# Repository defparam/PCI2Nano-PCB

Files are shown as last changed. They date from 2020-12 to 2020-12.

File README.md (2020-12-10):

# PCI2Nano Reference Platform

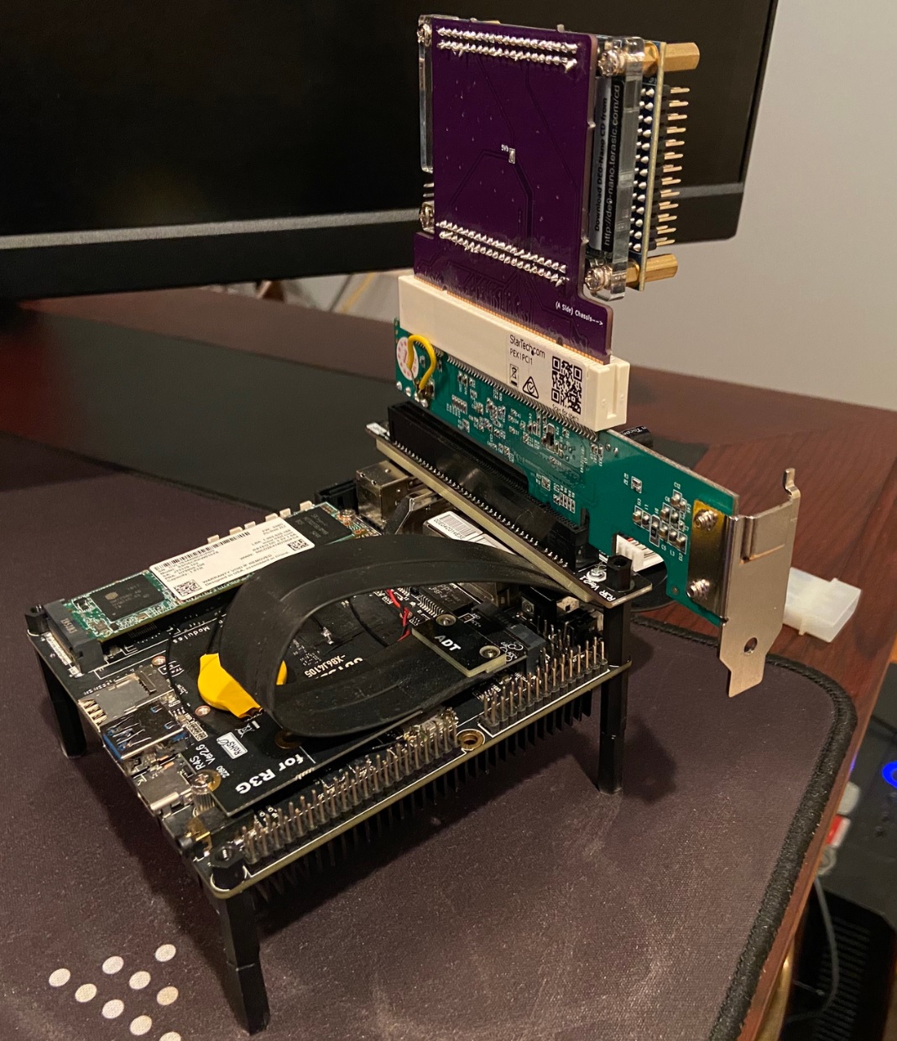
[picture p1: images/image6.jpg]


Welcome to the PCI2Nano Reference Platform repo. In this repo you'll find an inexpensive suggested Reference Platform for designing and testing PCI functions on a DE0-Nano FPGA to an x86 host. I have personally built/connected/tested every single one of these components and can confirm they work for fast iterative PCI development.

The design collateral that is included with this repo are the kicad design files for the PCI2Nano breakout board and a Quartus project that contains all the correct PCI pinout constraints for the PCI2Nano breakout board. This repo does not contain an actual PCI core written in verilog. For an example PCI core implementation with a UART check out the PCI2Nano-RTL repo here: https://github.com/defparam/PCI2Nano-RTL/

<br />This work is licensed under a <a rel="license" href="http://creativecommons.org/licenses/by-sa/4.0/">Creative Commons Attribution-ShareAlike 4.0 International License</a>.

# Demo
My l337-Communication Controller

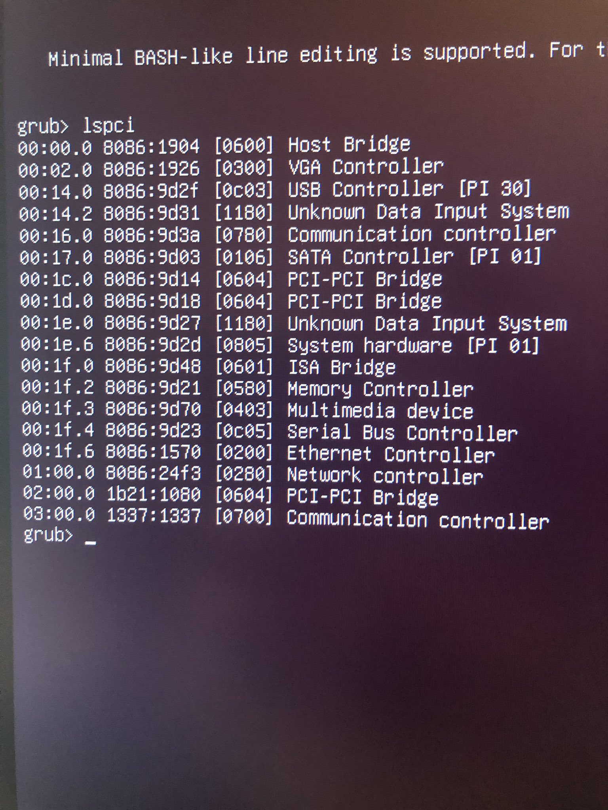
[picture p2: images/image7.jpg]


# Reference Platform Parts List
| Part |  Description| Price | 
|--|--|--|
| DE0-Nano |  FPGA Board|~$100.00
| Seeed Odyssey X86J4105 SBC | SIngle Board Computer | ~$185.00
|PCI2Nano Breakout PCB|Coverts PCI to DE0-Nano GPIO | ~$45 (OSHPark for 3)
|Startech PEX1PCI1| Converts PCIe to PCI | ~$40
|M.2 Key M Extender PCIE x16 | Break out M.2 to PCIe x16 | ~$32
2x 100mil 40-pin IDC sockets| Soldered to the PCB| ~$1-$2

# Directions
1) Mount the Extender cable into the Odyssey M.2 M Key slot. If you have standoffs you can affix the x16 connector of the extender to the SBC as shown in the picture above.
2) Mount the PEX1PCI1 onto the x16 connector. Supplying the molex power I believe is not required since it is used to power the 5V rails of a mounted PCI device, the PCI2Nano doesn't use this 5V rail (unless you bridge it to the Nano's 5V GPIO power pin via the board shunt). However it is best to power the nano through its USB cable
3) Connect the PCI2Nano breakout board to the DE0-Nano, make sure that the USB of the nano points in the correct direction as specified by the silkscreen
4) Connect the PCI side of the PCI2Nano onto the PEX1PCI1, make sure it is connected in the orientation as indicated by the silk screen. The arrow indicating the chassis side should be pointed to the externel side of the PEX1PCI1

# PCB board
There is a small amount of soldering involved with the PCB board to connect the 100mil IDC socket to the PCB board.

# Parts
The DE0-Nano:

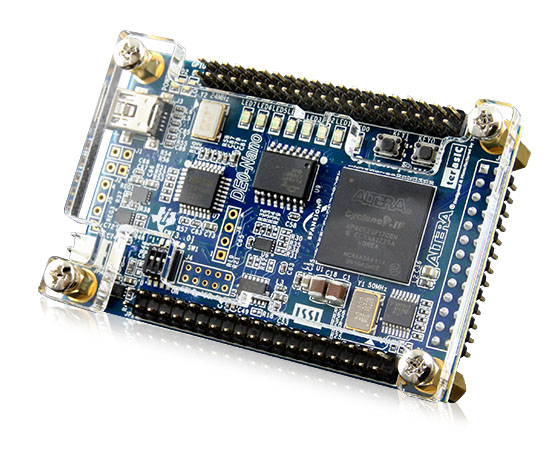
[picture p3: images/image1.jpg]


The PCI2Nano PCB:

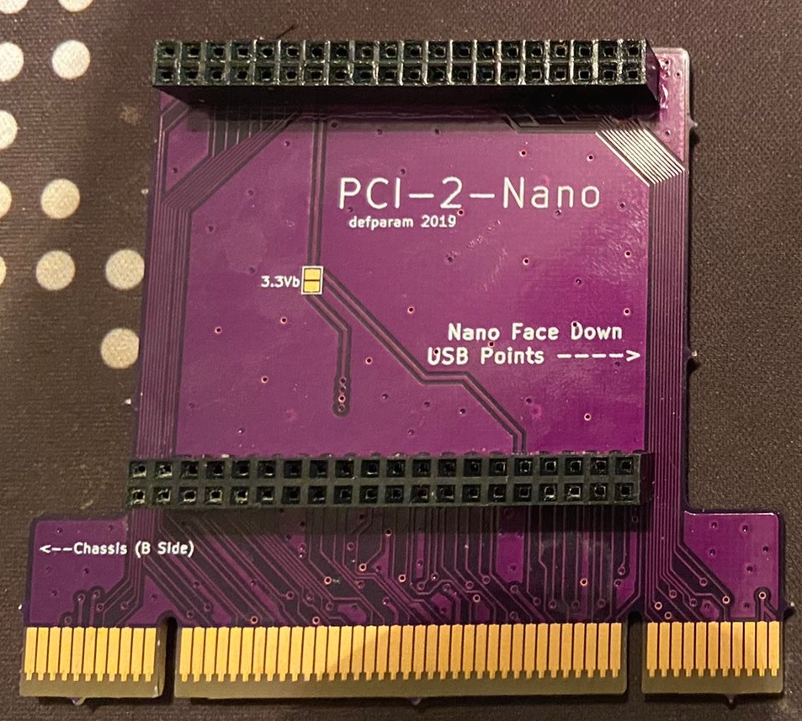
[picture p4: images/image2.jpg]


The PEX1PCI1 PCIe-2-PCI Bridge:

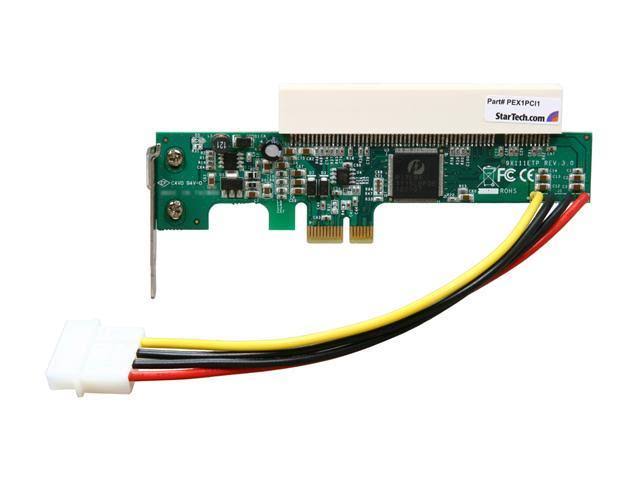
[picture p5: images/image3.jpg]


The Seeed Odyssey X86J4105 SBC:

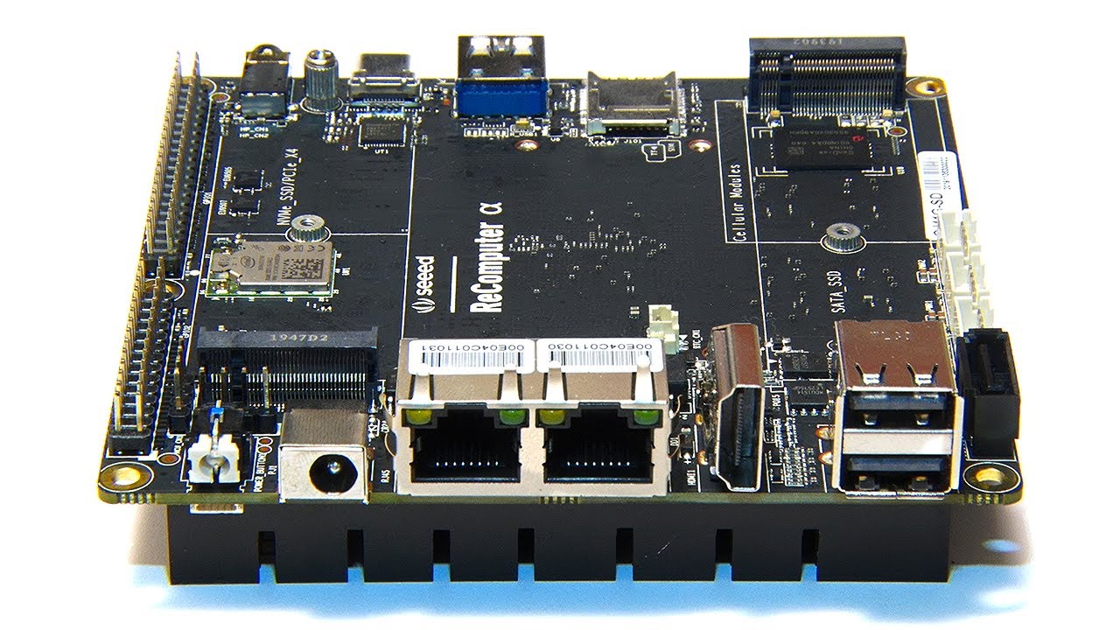
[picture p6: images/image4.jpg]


The M.2 Key M Extender PCIE x16:

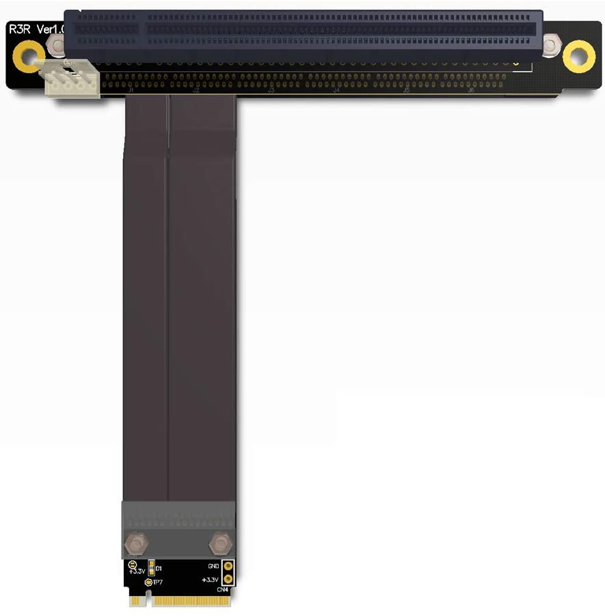
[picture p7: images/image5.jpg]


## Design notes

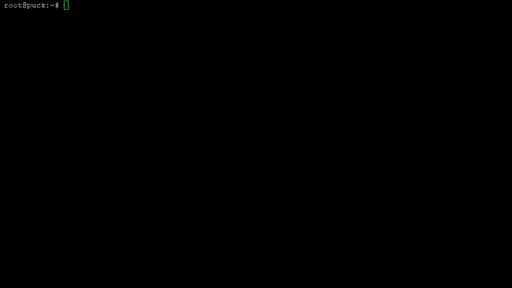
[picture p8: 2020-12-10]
images/pci2nano.gif

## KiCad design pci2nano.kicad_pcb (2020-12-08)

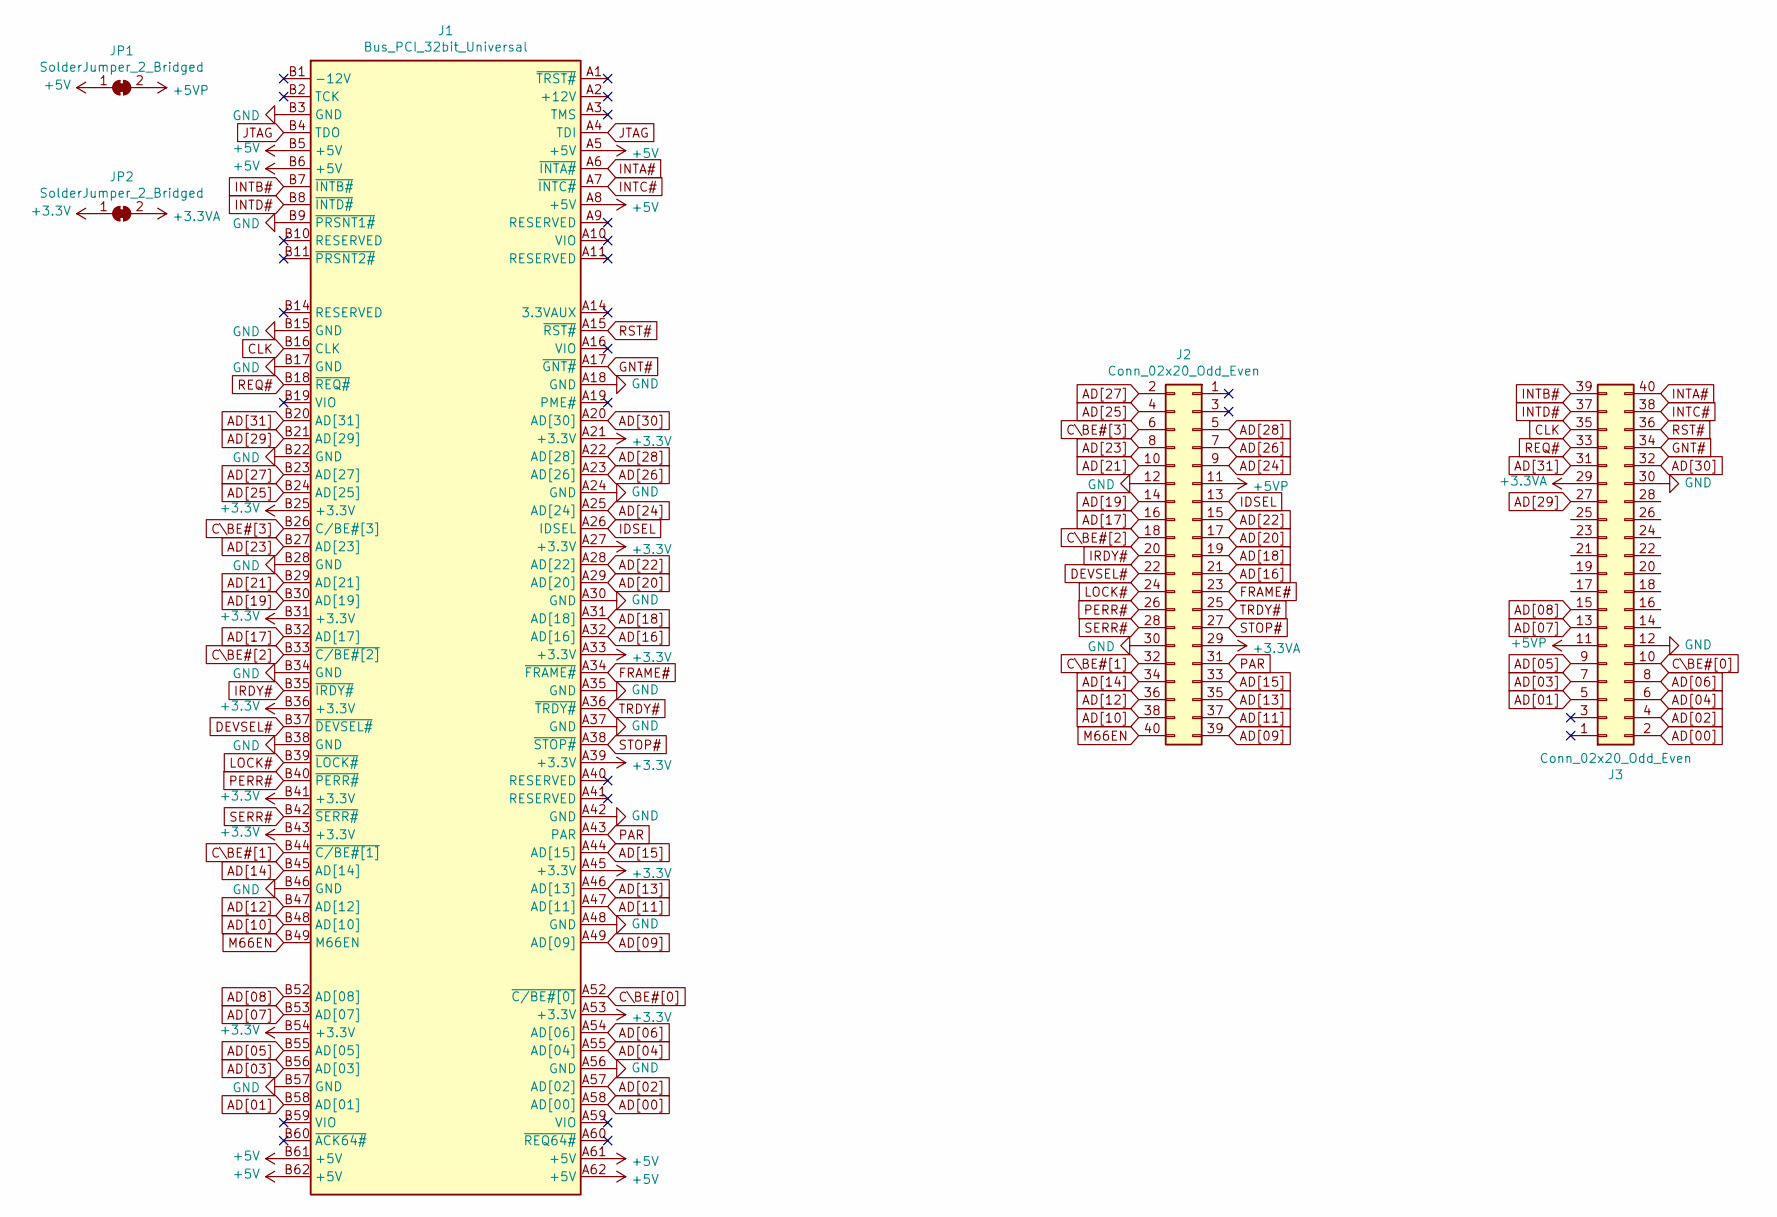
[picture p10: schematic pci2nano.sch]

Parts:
J1: Bus_PCI_32bit_Universal; BUS_PCI_UNIVERSAL
J2, J3: Conn_02x20_Odd_Even; PinHeader_2x20_P2.54mm_Vertical
JP1, JP2: SolderJumper_2_Bridged; SolderJumper-2_P1.3mm_Open_Pad1.0x1.5mm

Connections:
+3.3VA: J2.29, J3.29, JP2.2 (B)
+3V3: J1.A21 (+3.3V), J1.A27 (+3.3V), J1.A33 (+3.3V), J1.A39 (+3.3V), J1.A45 (+3.3V), J1.A53 (+3.3V), J1.B25 (+3.3V), J1.B31 (+3.3V), J1.B36 (+3.3V), J1.B41 (+3.3V), J1.B43 (+3.3V), J1.B54 (+3.3V), JP2.1 (A)
+5V: J1.A5 (+5V), J1.A8 (+5V), J1.A61 (+5V), J1.A62 (+5V), J1.B5 (+5V), J1.B6 (+5V), J1.B61 (+5V), J1.B62 (+5V), JP1.1 (A)
+5VP: J2.11, J3.11, JP1.2 (B)
AD[00]: J1.A58 (AD[00]), J3.2
AD[01]: J1.B58 (AD[01]), J3.5
AD[02]: J1.A57 (AD[02]), J3.4
AD[03]: J1.B56 (AD[03]), J3.7
AD[04]: J1.A55 (AD[04]), J3.6
AD[05]: J1.B55 (AD[05]), J3.9
AD[06]: J1.A54 (AD[06]), J3.8
AD[07]: J1.B53 (AD[07]), J3.13
AD[08]: J1.B52 (AD[08]), J3.15
AD[09]: J1.A49 (AD[09]), J2.39
AD[10]: J1.B48 (AD[10]), J2.38
AD[11]: J1.A47 (AD[11]), J2.37
AD[12]: J1.B47 (AD[12]), J2.36
AD[13]: J1.A46 (AD[13]), J2.35
AD[14]: J1.B45 (AD[14]), J2.34
AD[15]: J1.A44 (AD[15]), J2.33
AD[16]: J1.A32 (AD[16]), J2.21
AD[17]: J1.B32 (AD[17]), J2.16
AD[18]: J1.A31 (AD[18]), J2.19
AD[19]: J1.B30 (AD[19]), J2.14
AD[20]: J1.A29 (AD[20]), J2.17
AD[21]: J1.B29 (AD[21]), J2.10
AD[22]: J1.A28 (AD[22]), J2.15
AD[23]: J1.B27 (AD[23]), J2.8
AD[24]: J1.A25 (AD[24]), J2.9
AD[25]: J1.B24 (AD[25]), J2.4
AD[26]: J1.A23 (AD[26]), J2.7
AD[27]: J1.B23 (AD[27]), J2.2
AD[28]: J1.A22 (AD[28]), J2.5
AD[29]: J1.B21 (AD[29]), J3.27
AD[30]: J1.A20 (AD[30]), J3.32
AD[31]: J1.B20 (AD[31]), J3.31
CLK: J1.B16 (CLK), J3.35
C\BE#[0]: J1.A52 (~C/BE#[0]), J3.10
C\BE#[1]: J1.B44 (~C/BE#[1]), J2.32
C\BE#[2]: J1.B33 (~C/BE#[2]), J2.18
C\BE#[3]: J1.B26 (C/BE#[3]), J2.6
DEVSEL#: J1.B37 (~DEVSEL#), J2.22
FRAME#: J1.A34 (~FRAME#), J2.23
GND: J1.A18 (GND), J1.A24 (GND), J1.A30 (GND), J1.A35 (GND), J1.A37 (GND), J1.A42 (GND), J1.A48 (GND), J1.A56 (GND), J1.B3 (GND), J1.B9 (~PRSNT1#), J1.B15 (GND), J1.B17 (GND), J1.B22 (GND), J1.B28 (GND), J1.B34 (GND), J1.B38 (GND), J1.B46 (GND), J1.B57 (GND), J2.12, J2.30, J3.12, J3.30
GNT#: J1.A17 (~GNT#), J3.34
IDSEL: J1.A26 (IDSEL), J2.13
INTA#: J1.A6 (~INTA#), J3.40
INTB#: J1.B7 (~INTB#), J3.39
INTC#: J1.A7 (~INTC#), J3.38
INTD#: J1.B8 (~INTD#), J3.37
IRDY#: J1.B35 (~IRDY#), J2.20
JTAG: J1.A4 (TDI), J1.B4 (TDO)
LOCK#: J1.B39 (~LOCK#), J2.24
M66EN: J1.B49 (M66EN), J2.40
PAR: J1.A43 (PAR), J2.31
PERR#: J1.B40 (~PERR#), J2.26
REQ#: J1.B18 (~REQ#), J3.33
RST#: J1.A15 (~RST#), J3.36
SERR#: J1.B42 (~SERR#), J2.28
STOP#: J1.A38 (~STOP#), J2.27
TRDY#: J1.A36 (~TRDY#), J2.25

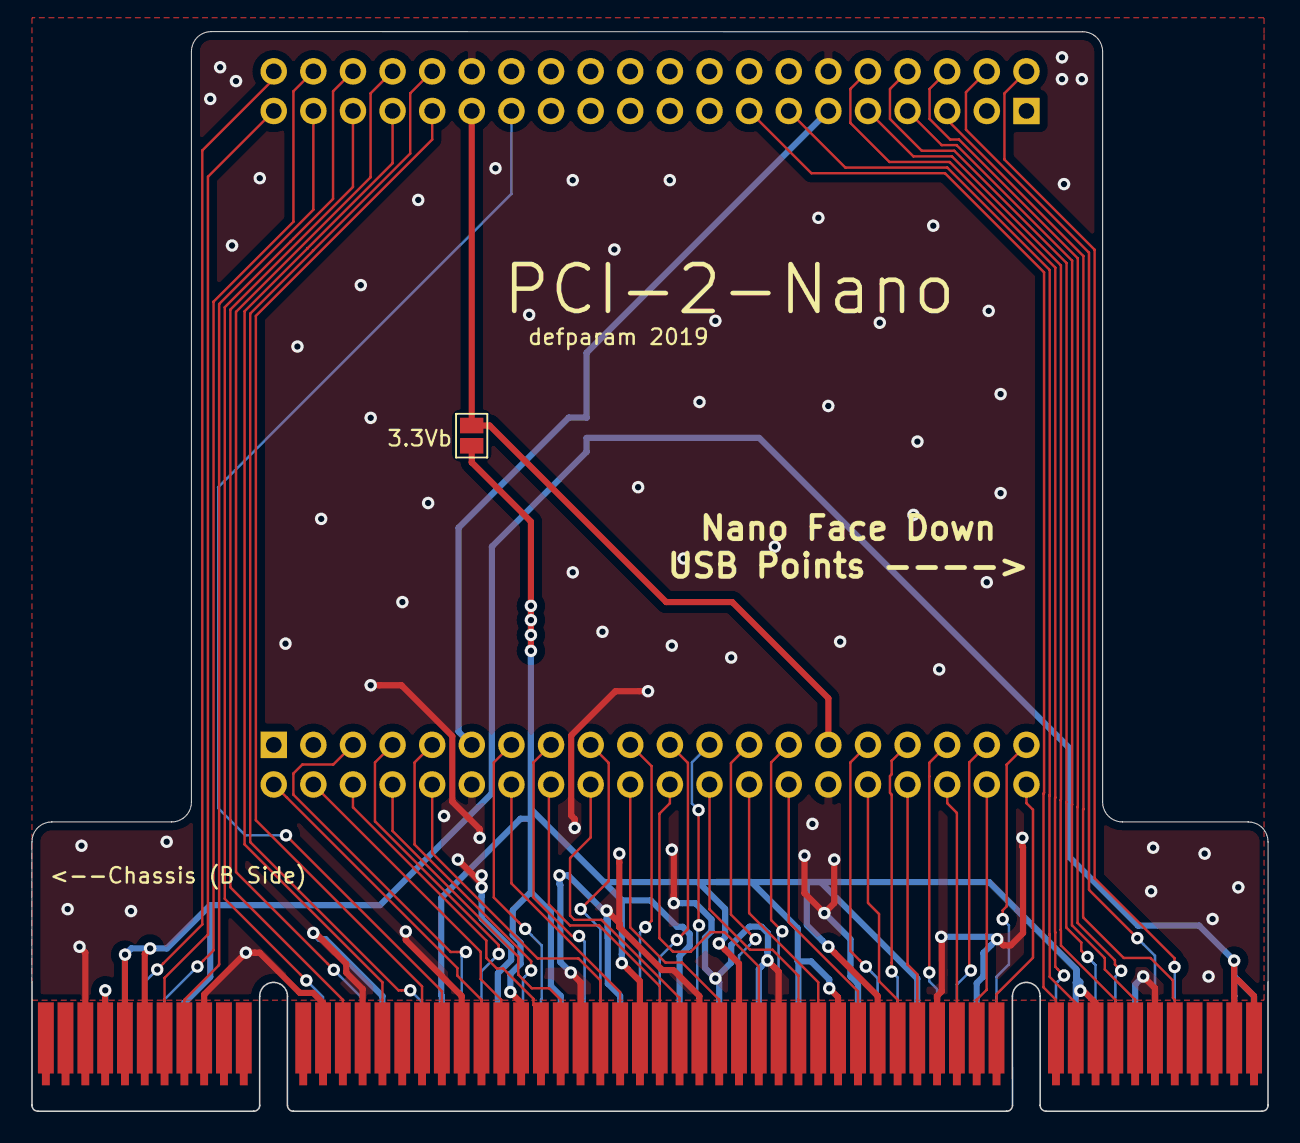
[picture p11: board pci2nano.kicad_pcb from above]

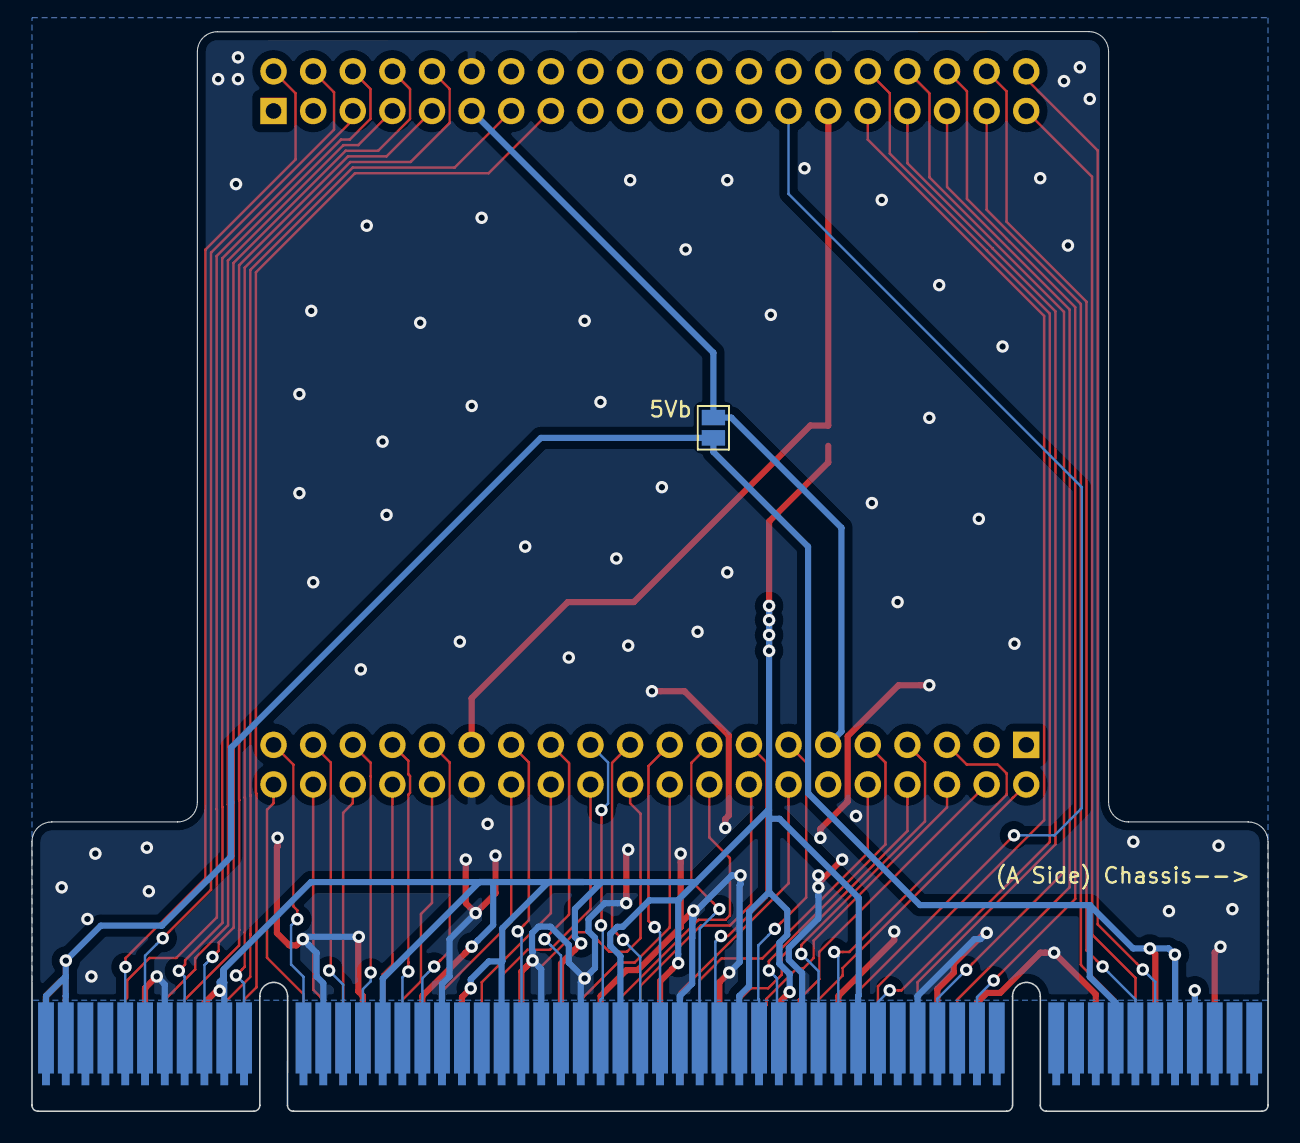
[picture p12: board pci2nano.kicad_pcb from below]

Board: 2 copper layers, 79.2 x 69.2 mm, 5 parts (3 on the bottom side), 61 nets.

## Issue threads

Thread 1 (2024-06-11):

Niggard [greedy] vendors

hergljkds, 2024-06-11:
The prices referenced on the PCI2Nano-PCB  splash page are much better than those that I am seeing in this captive portal (interstate commerce clause violating state of PA, with DHS sandbox)... [2x markups common to support cons and other MITMA scum]

Part                  Description                 Price [listed]              [actual (2024-06)]
DE0-Nano        FPGA Board 	            ~$100.00                  $259.73 *

* https://www.amazon.com/Programmable-Logic-Development-Tools-DE0-Nano/dp/B09PXYYVRP
...also note the Fahrenheit 451 reference with a part number of "451."  When did the government gain a First Ammendment right to add political commentary to items sold?  When did the government gain the right to add over a 100% non-described tax to items that they do not want sold?

Seeed Odyssey X86J4105 SBC 	SIngle Board Computer 	~$185.00 $398.22

* https://www.amazon.com/seeed-studio-Processor-Dual-Band-Bluetooth/dp/B089NV4PD5

...notice the trend, niggard pricing (2x+ markup, plus shipping)... so that some scum (MITMA con) can buy a second device.  Never underestimate how blatent cons are in their effort to promote mimicry and fraud.  Does the FBI want to do it's job and start killing communist cons in the US?

To those that are conning me, I will kill you and your families.

Best,

PF

Closed 2024-06-11.

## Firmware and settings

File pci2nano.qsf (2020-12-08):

#============================================================
# PCI2NANO Shell Design by Evan Custodio (@defparam)
#============================================================

set_global_assignment -name FAMILY "Cyclone IV E"
set_global_assignment -name DEVICE EP4CE22F17C6
set_global_assignment -name TOP_LEVEL_ENTITY pci2nano
set_global_assignment -name ORIGINAL_QUARTUS_VERSION 16.0.2
set_global_assignment -name LAST_QUARTUS_VERSION 13.1
set_global_assignment -name PROJECT_CREATION_TIME_DATE "17:42:43 OCTOBER 12,2019"
set_global_assignment -name DEVICE_FILTER_PACKAGE FBGA
set_global_assignment -name DEVICE_FILTER_PIN_COUNT 256
set_global_assignment -name DEVICE_FILTER_SPEED_GRADE 6
set_global_assignment -name CYCLONEII_RESERVE_NCEO_AFTER_CONFIGURATION "USE AS REGULAR IO"
set_global_assignment -name RESERVE_FLASH_NCE_AFTER_CONFIGURATION "USE AS REGULAR IO"
set_global_assignment -name RESERVE_DATA0_AFTER_CONFIGURATION "USE AS REGULAR IO"
set_global_assignment -name RESERVE_DATA1_AFTER_CONFIGURATION "USE AS REGULAR IO"
set_global_assignment -name RESERVE_DCLK_AFTER_CONFIGURATION "USE AS REGULAR IO"

#============================================================
# CLOCK
#============================================================
set_location_assignment PIN_R8 -to CLOCK_50

#============================================================
# LED
#============================================================
set_location_assignment PIN_A15 -to LED[0]
set_location_assignment PIN_A13 -to LED[1]
set_location_assignment PIN_B13 -to LED[2]
set_location_assignment PIN_A11 -to LED[3]
set_location_assignment PIN_D1 -to LED[4]
set_location_assignment PIN_F3 -to LED[5]
set_location_assignment PIN_B1 -to LED[6]
set_location_assignment PIN_L3 -to LED[7]

#============================================================
# KEY
#============================================================
set_location_assignment PIN_J15 -to KEY[0]
set_location_assignment PIN_E1 -to KEY[1]

#============================================================
# SW
#============================================================
set_location_assignment PIN_M1 -to SW[0]
set_location_assignment PIN_T8 -to SW[1]
set_location_assignment PIN_B9 -to SW[2]
set_location_assignment PIN_M15 -to SW[3]

#============================================================
# SDRAM
#============================================================
set_location_assignment PIN_P2 -to DRAM_ADDR[0]
set_location_assignment PIN_N5 -to DRAM_ADDR[1]
set_location_assignment PIN_N6 -to DRAM_ADDR[2]
set_location_assignment PIN_M8 -to DRAM_ADDR[3]
set_location_assignment PIN_P8 -to DRAM_ADDR[4]
set_location_assignment PIN_T7 -to DRAM_ADDR[5]
set_location_assignment PIN_N8 -to DRAM_ADDR[6]
set_location_assignment PIN_T6 -to DRAM_ADDR[7]
set_location_assignment PIN_R1 -to DRAM_ADDR[8]
set_location_assignment PIN_P1 -to DRAM_ADDR[9]
set_location_assignment PIN_N2 -to DRAM_ADDR[10]
set_location_assignment PIN_N1 -to DRAM_ADDR[11]
set_location_assignment PIN_L4 -to DRAM_ADDR[12]
set_location_assignment PIN_M7 -to DRAM_BA[0]
set_location_assignment PIN_M6 -to DRAM_BA[1]
set_location_assignment PIN_L1 -to DRAM_CAS_N
set_location_assignment PIN_L7 -to DRAM_CKE
set_location_assignment PIN_R4 -to DRAM_CLK
set_location_assignment PIN_P6 -to DRAM_CS_N
set_location_assignment PIN_G2 -to DRAM_DQ[0]
set_location_assignment PIN_G1 -to DRAM_DQ[1]
set_location_assignment PIN_L8 -to DRAM_DQ[2]
set_location_assignment PIN_K5 -to DRAM_DQ[3]
set_location_assignment PIN_K2 -to DRAM_DQ[4]
set_location_assignment PIN_J2 -to DRAM_DQ[5]
set_location_assignment PIN_J1 -to DRAM_DQ[6]
set_location_assignment PIN_R7 -to DRAM_DQ[7]
set_location_assignment PIN_T4 -to DRAM_DQ[8]
set_location_assignment PIN_T2 -to DRAM_DQ[9]
set_location_assignment PIN_T3 -to DRAM_DQ[10]
set_location_assignment PIN_R3 -to DRAM_DQ[11]
set_location_assignment PIN_R5 -to DRAM_DQ[12]
set_location_assignment PIN_P3 -to DRAM_DQ[13]
set_location_assignment PIN_N3 -to DRAM_DQ[14]
set_location_assignment PIN_K1 -to DRAM_DQ[15]
set_location_assignment PIN_R6 -to DRAM_DQM[0]
set_location_assignment PIN_T5 -to DRAM_DQM[1]
set_location_assignment PIN_L2 -to DRAM_RAS_N
set_location_assignment PIN_C2 -to DRAM_WE_N

#============================================================
# EPCS
#============================================================
set_location_assignment PIN_C1 -to EPCS_ASDO
set_location_assignment PIN_H2 -to EPCS_DATA0
set_location_assignment PIN_H1 -to EPCS_DCLK
set_location_assignment PIN_D2 -to EPCS_NCSO

#============================================================
# EEPROM
#============================================================
set_location_assignment PIN_F2 -to I2C_SCLK
set_location_assignment PIN_F1 -to I2C_SDAT

#============================================================
# 2x13 GPIO Header
#============================================================
set_location_assignment PIN_A14 -to GPIO_2[0]
set_location_assignment PIN_B16 -to GPIO_2[1]
set_location_assignment PIN_C14 -to GPIO_2[2]
set_location_assignment PIN_C16 -to GPIO_2[3]
set_location_assignment PIN_C15 -to GPIO_2[4]
set_location_assignment PIN_D16 -to GPIO_2[5]
set_location_assignment PIN_D15 -to GPIO_2[6]
set_location_assignment PIN_D14 -to GPIO_2[7]
set_location_assignment PIN_F15 -to GPIO_2[8]
set_location_assignment PIN_F16 -to GPIO_2[9]
set_location_assignment PIN_F14 -to GPIO_2[10]
set_location_assignment PIN_G16 -to GPIO_2[11]
set_location_assignment PIN_G15 -to GPIO_2[12]
set_location_assignment PIN_E15 -to GPIO_2_IN[0]
set_location_assignment PIN_E16 -to GPIO_2_IN[1]
set_location_assignment PIN_M16 -to GPIO_2_IN[2]

#============================================================
# GPIO map for PCI-specific signals
#============================================================

set_location_assignment PIN_A8 -to PCI_0_IN[0]
set_location_assignment PIN_D3 -to AD[0]
set_location_assignment PIN_B8 -to PCI_0_IN[1]
set_location_assignment PIN_C3 -to AD[2]
set_location_assignment PIN_A2 -to AD[1]
set_location_assignment PIN_A3 -to AD[4]
set_location_assignment PIN_B3 -to AD[3]
set_location_assignment PIN_B4 -to AD[6]
set_location_assignment PIN_A4 -to AD[5]
set_location_assignment PIN_B5 -to CBEn[0]


set_location_assignment PIN_A5 -to AD[7]
set_location_assignment PIN_D5 -to PCI_1_[9]
set_location_assignment PIN_B6 -to AD[8]
set_location_assignment PIN_A6 -to PCI_1_[11]
set_location_assignment PIN_B7 -to PCI_1_[12]
set_location_assignment PIN_D6 -to PCI_1_[13]
set_location_assignment PIN_A7 -to PCI_1_[14]
set_location_assignment PIN_C6 -to PCI_1_[15]
set_location_assignment PIN_C8 -to PCI_1_[16]
set_location_assignment PIN_E6 -to PCI_1_[17]
set_location_assignment PIN_E7 -to PCI_1_[18]
set_location_assignment PIN_D8 -to PCI_1_[19]
set_location_assignment PIN_E8 -to PCI_1_[20]
set_location_assignment PIN_F8 -to PCI_1_[21]
set_location_assignment PIN_F9 -to AD[29]
set_location_assignment PIN_E9 -to PCI_1_[23]
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
